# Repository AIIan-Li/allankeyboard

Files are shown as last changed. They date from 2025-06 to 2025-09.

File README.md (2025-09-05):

# Allan's keyboard
### About:
A 75% keyboard with a custom case. All parts under $150 USD, uses screw in stabilisers, and has akko v3 yellow switches along with M3 heatset inserts and screws. I made this project to learn more about CAD and making hardware projects. I thought it would be a reasonable next step after a macropad (was way harder actually) however I got to challenge myself and learn new things. 

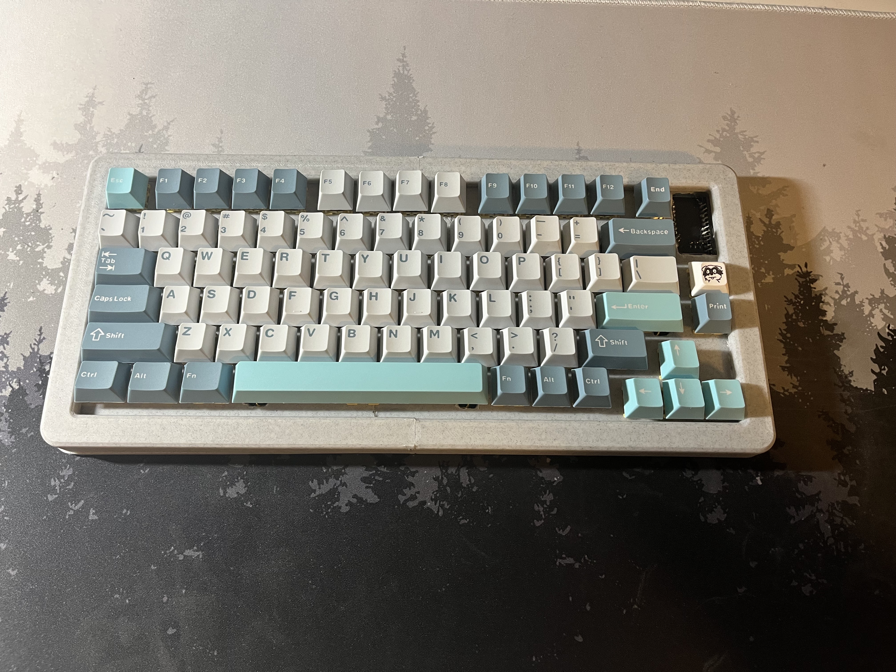
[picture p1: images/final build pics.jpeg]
final build

[project demo](https://youtu.be/CJazeotiTts)
[good project demo](https://youtu.be/POquT2XbD1o)
### Case:

The case was made in Fusion 360 and is gasket mounted. 8 screws to ensure the keyboard is secure when printing in two parts. 

### Firmware:

The firmware was made with KMK however I intend to recreate firmware in ZMK for full bluetooth capabilities( I am currently learning as I don't want to just copilot/vibecode everything)

### Images:

Schematic
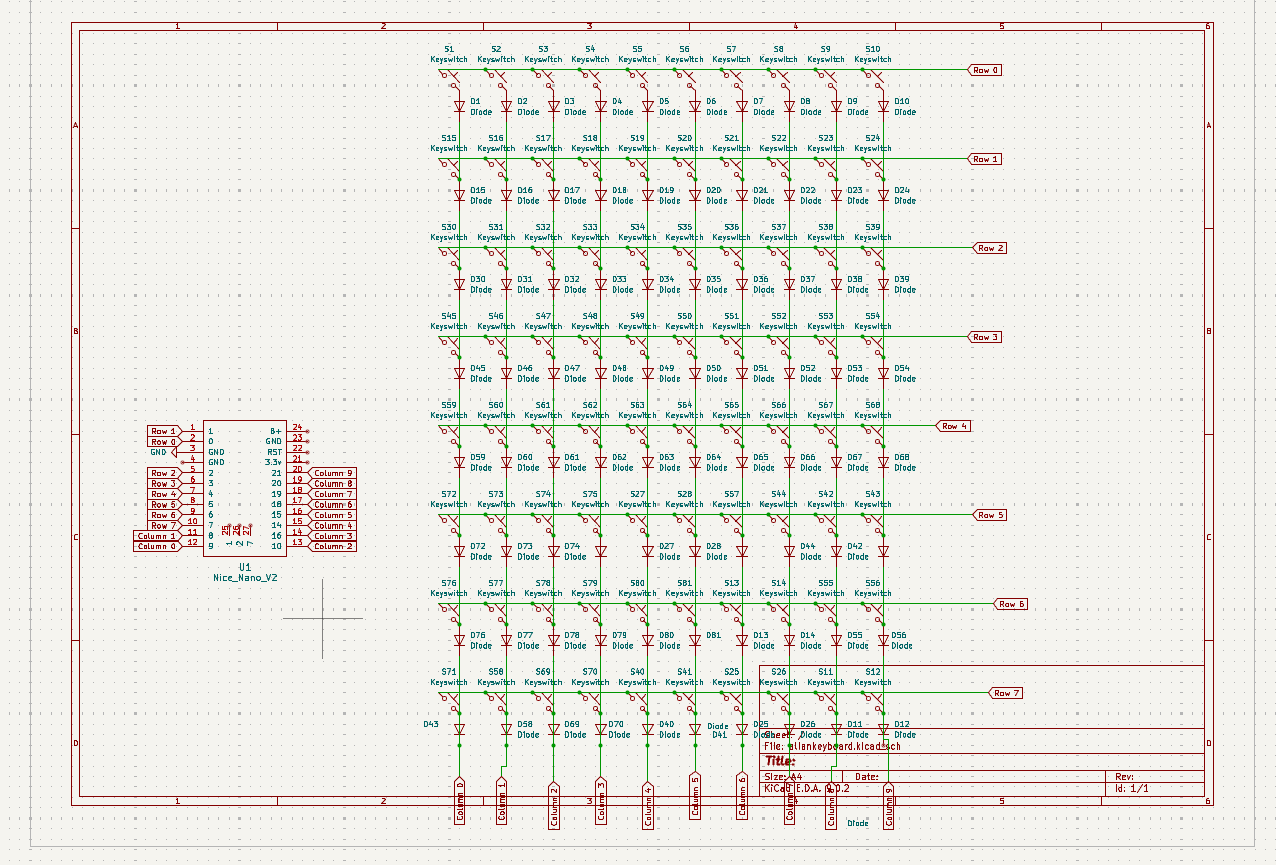
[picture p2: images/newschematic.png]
schematic


PCB
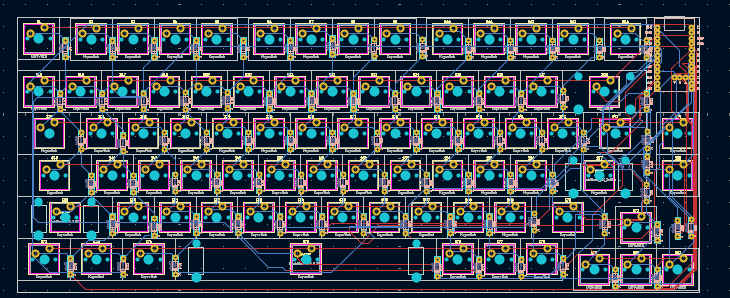
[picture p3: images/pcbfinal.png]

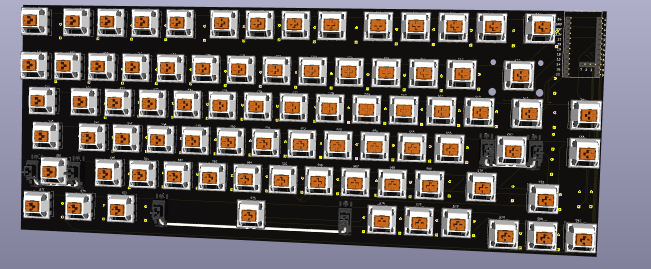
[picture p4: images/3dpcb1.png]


Case
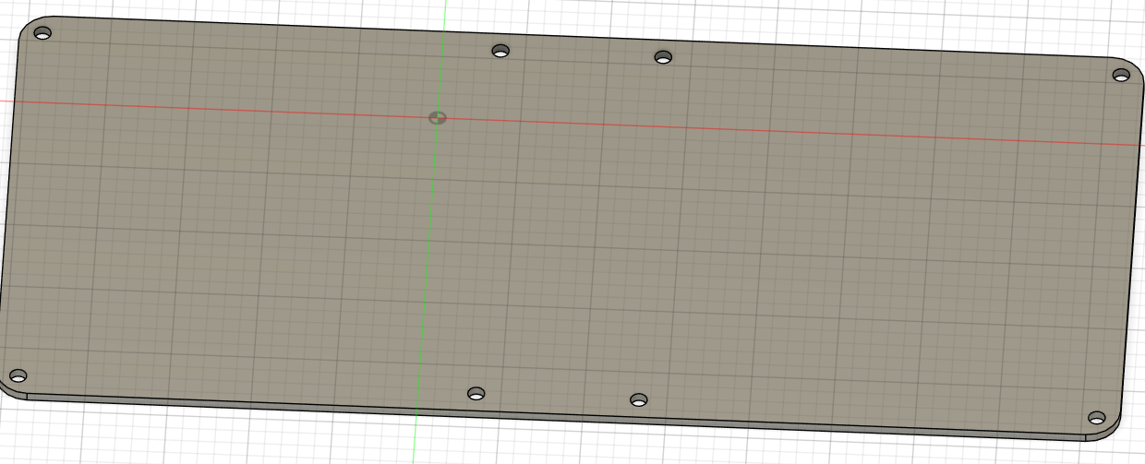
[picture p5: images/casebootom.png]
case

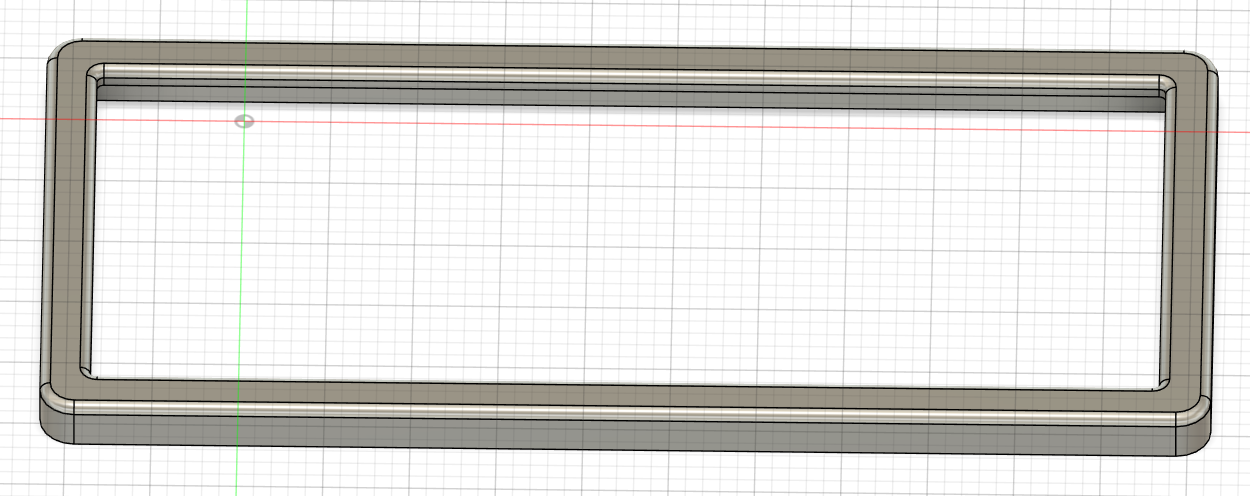
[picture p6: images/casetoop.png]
case

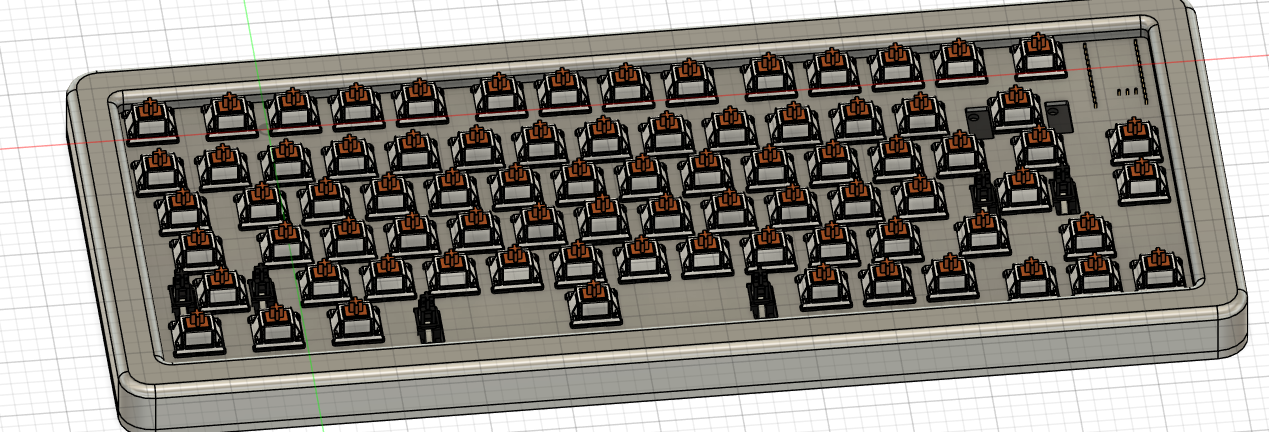
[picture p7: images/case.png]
case


### BOM:
| Item | Cost (USD) | Cost (CAD) | Link |
| --- | --- | --- | --- |
| Akko V3 Cream Yellow Switches | \$33.00 | \$45.00 | [https://www.amazon.ca/Akko-Keyboard-Dustproof-Mechanical-Switches/dp/B0C3H8NVJV/](https://www.amazon.ca/Akko-Keyboard-Dustproof-Mechanical-Switches/dp/B0C3H8NVJV/) |
| 3D Printer Filament (PLA 1kg) | \$21.00 | \$28.00 | [https://www.amazon.ca/ELEGOO-Filament-Dimensional-Accuracy-Compatible/dp/B0BM4F65SL/](https://www.amazon.ca/ELEGOO-Filament-Dimensional-Accuracy-Compatible/dp/B0BM4F65SL/) |
| PCB x5 (min quantity) | \$0.00 | \$0.00 | [https://jlcpcb.com](https://jlcpcb.com) |
| 1N4148 Diodes x100 | \$1.50 | \$2.00 | [https://www.aliexpress.com/item/1005003194692663.html](https://www.aliexpress.com/item/1005003194692663.html) |
| Durock V3 Stabilizers | \$10.00 | \$13.00 | [https://www.aliexpress.com/item/1005002192386317.html](https://www.aliexpress.com/item/1005002192386317.html) |
| Heatset Inserts | \$5.10 | \$7.00 | [https://www.aliexpress.com/item/1005006472962973.html](https://www.aliexpress.com/item/1005006472962973.html) |
| nice!nano v2 | \$44.00 | \$60.00 | [https://typeractive.xyz/products/nice-nano](https://typeractive.xyz/products/nice-nano) |
| Keycaps | \$9.00 | \$12.00 | [https://www.aliexpress.com/item/1005007321700850.html](https://www.aliexpress.com/item/1005007321700850.html) |
| Screws | \$1.80 | \$2.50 | [https://www.aliexpress.com/item/4000056753202.html](https://www.aliexpress.com/item/4000056753202.html) |
| | | | |

| **Total (Shipping included)** | **\$123.60** | **\$170.00** |                                                                                                                                                                              |

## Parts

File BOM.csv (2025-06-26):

Bill of Materials / Allan keyboard
Allan Li
June 24 2025
Item Name | Purpose | Item Source | Quantity | cost USD(w/ shipping) | cost CAD(W/ shipping) | link
Akko V3 cream yellow switches | Mechanical switches | amazon | 2 | $33 | $45 | https://www.amazon.ca/Akko-Keyboard-Dustproof-Mechanical-Switches/dp/B0C3H8NVJV/
3D Printer Filament (PLA 1kg) | Print Case | Amazon | 1 | $21 | $28 | https://www.amazon.ca/ELEGOO-Filament-Dimensional-Accuracy-Compatible/dp/B0BM4F65SL/
PCB x5 (min quantity) | the pcb | JLCPCB | 1 | $0 | 0 | jlcpcb.com (free)
1N4148 Diodes x100 | they are diodes | Aliexpress | 2 | $1.5 | $2 | https://www.aliexpress.com/item/1005003194692663.html?
Durock V3 Stabilizers | Stability for longer keys | aliexpress | 1 | $10 | $13 | https://www.aliexpress.com/item/1005002192386317.html?
heatset inserts | for screwing in the screws | aliexpress | 1 | $5.1 | $7 | https://www.aliexpress.com/item/1005006472962973.html?
nice!nanov2 | mcu | typeractive | 1 | $44 | $60 | https://typeractive.xyz/products/nice-nano
keycaps | to click | aliexpress | 1 | $9 | $12 | https://www.aliexpress.com/item/1005007321700850.html?
screw | to secure case | aliexpress | 1 | 1.8 | 2.5 | https://www.aliexpress.com/item/4000056753202.html?
TOTAL |  |  |  | $123.6 | $170 | Shipping included even without coupons comes out to 143.6 USD

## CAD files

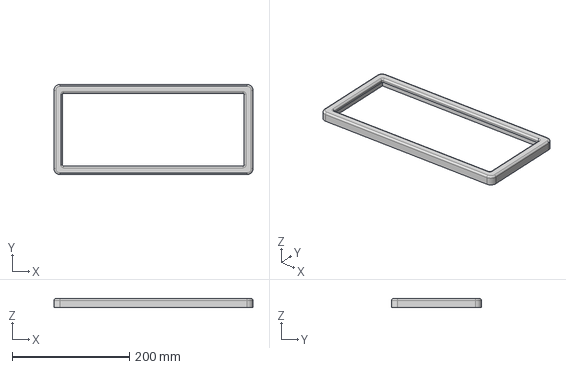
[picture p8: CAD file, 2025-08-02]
cad/super good casetop.step
339.0 x 153.5 x 15.0 mm

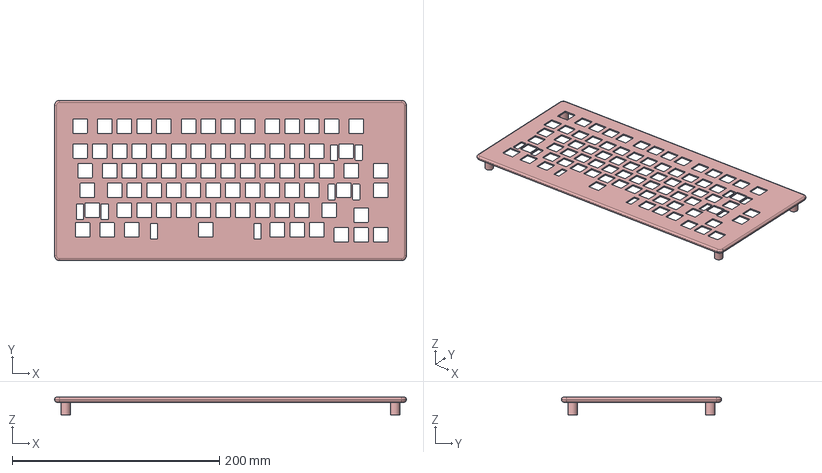
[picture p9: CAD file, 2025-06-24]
production/keyboard-top.step
340.0 x 155.0 x 17.0 mm

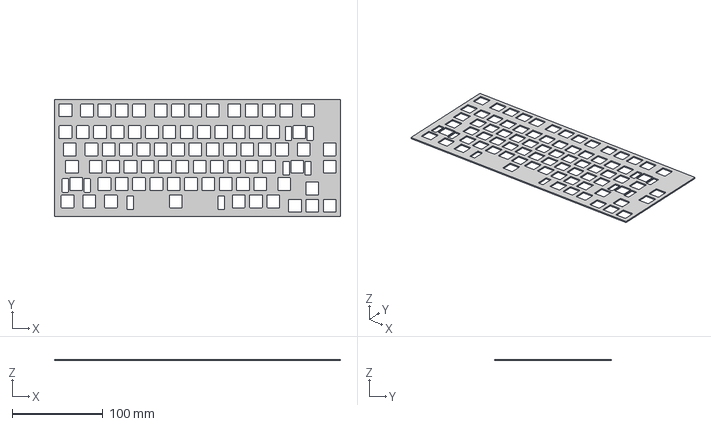
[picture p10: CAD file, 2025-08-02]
cad/plate-good.step
314.5 x 129.0 x 1.50 mm

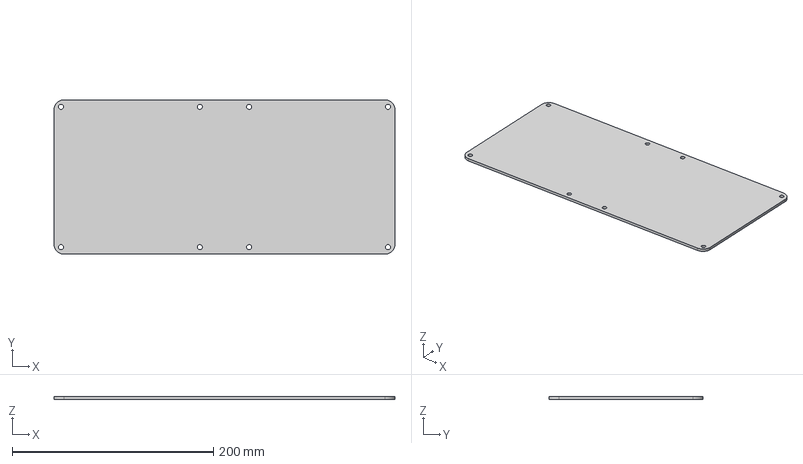
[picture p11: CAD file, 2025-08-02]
cad/super good casebottom.step
339.0 x 153.5 x 3.00 mm

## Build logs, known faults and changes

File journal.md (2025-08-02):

---
title: "Allan keyboard"
author: "Allan Li"
description: "Allan keyboard is a keyboard made for Allan"
created_at: "2025-06-09"
---
**Total time spent:1070 mins| 18 hours**
**Total time spent building: 4 hours** 

##June 9: research and getting started

So this is my first time making a keyboard, so I decided to do some thorough research to make sure that I fully understood everything, and made it how I wanted.
I'm thinking of a 75% keyboard, specificaly something similar to Epomakers, minus the rotary encoder.
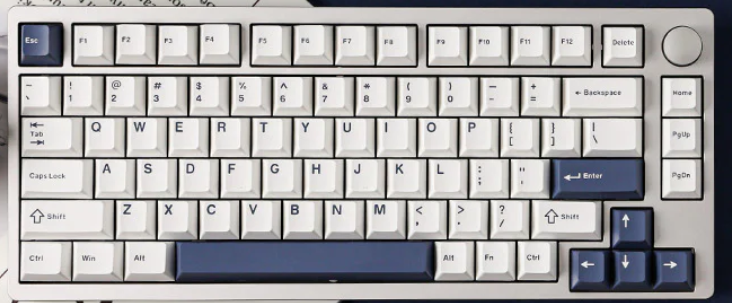
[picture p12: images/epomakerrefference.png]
refference image


I made an initial sketch for the matrix I also decided on the Nice Nano as the mcu
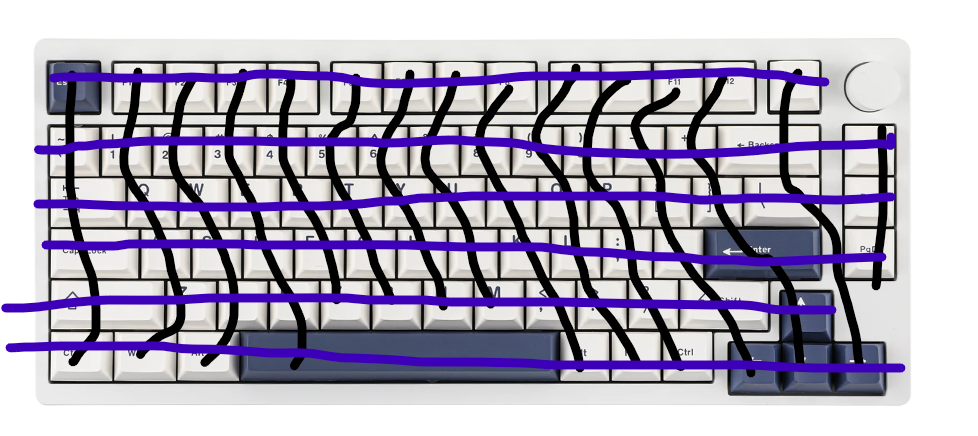
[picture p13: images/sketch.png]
matrix sketch

*Total time spent: 30 min*

##June 9: making the schematics

Not much to say, made the matrix and connected everything.
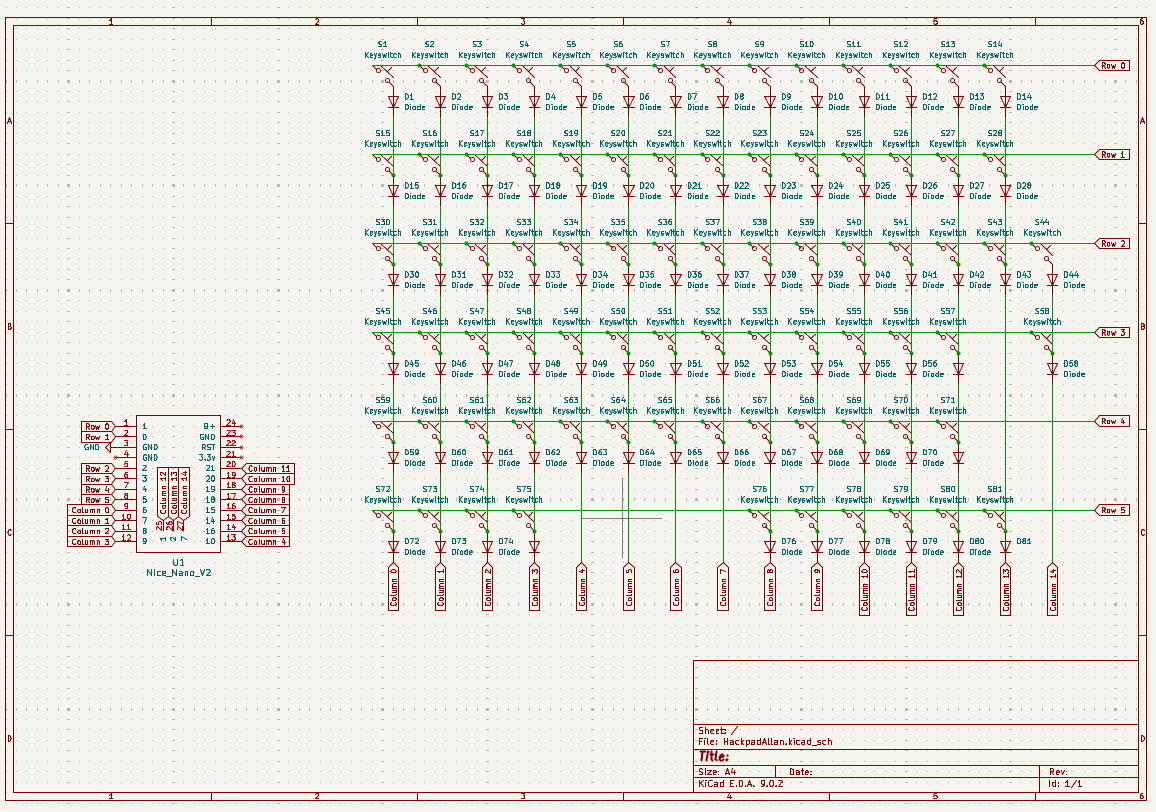
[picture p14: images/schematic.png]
schematic


*Total time spent:90 mins*

##June 10: starting the pcb

I started off by creating my design in Keyboard Layout Editor, then spent time trying to import it into KiCad.
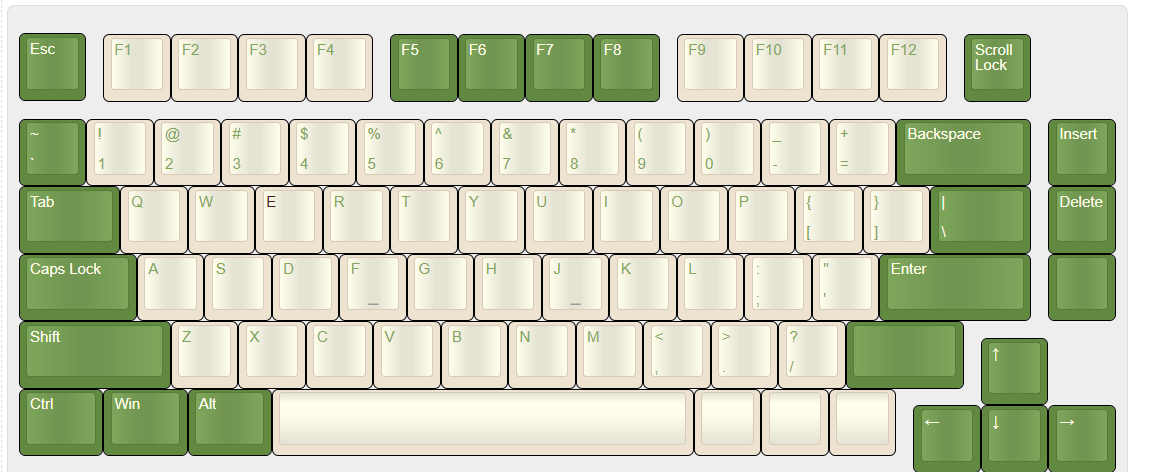
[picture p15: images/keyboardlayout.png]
KLE image


Took a really long time, I kept having problems with using the keboard placer plugin in Kicad,
had to redo footprints a bunch, set annotations and rearrange my schematic.
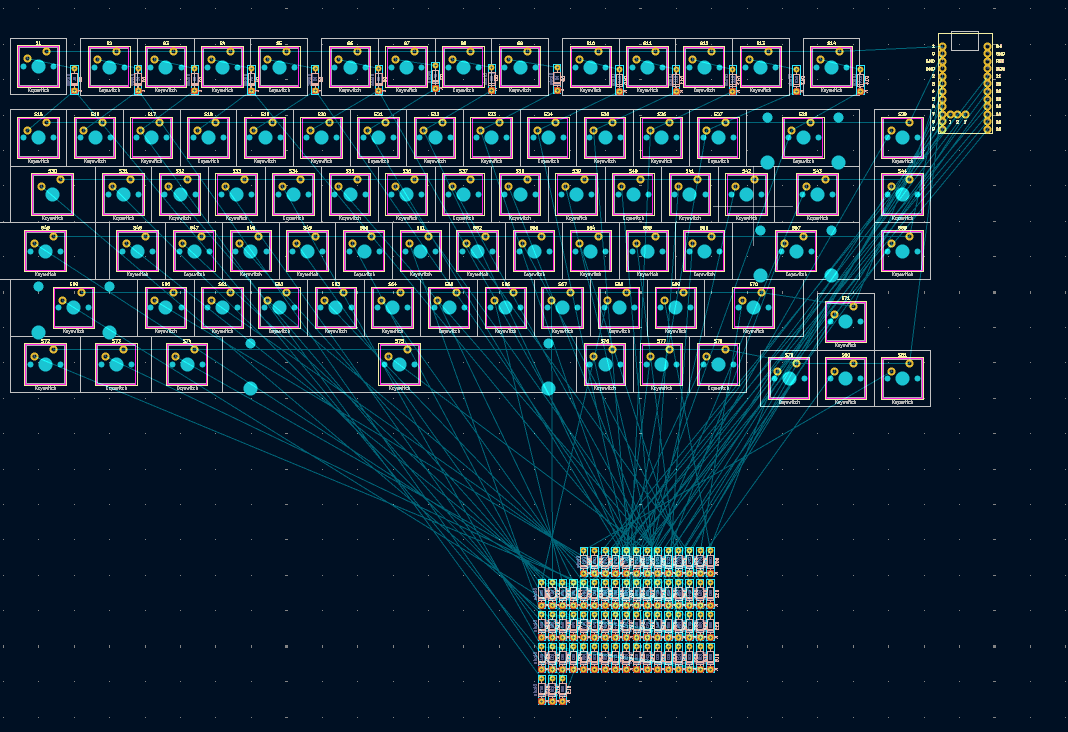
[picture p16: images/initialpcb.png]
initial pcb

Only have to move all diodes and route traces

Update: closed the window and clicked discard change because I was sure i only made one small thing. Will be restarting but oh well.

*Total time spent: 180 mins*

##june 11: Finishing the pcb

Finished positioning everything and routing all the traces. (made sure to save this time)

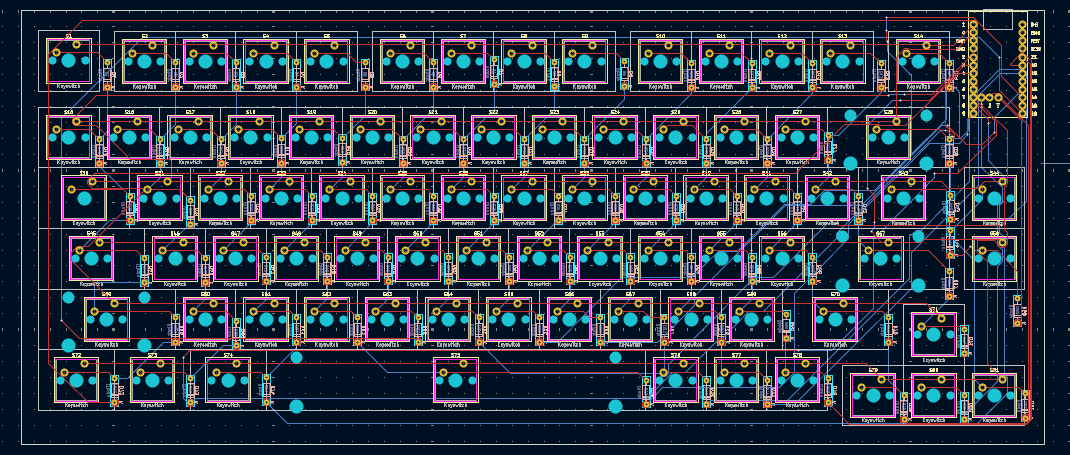
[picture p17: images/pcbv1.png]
pcb v1


Had a problem with the switches for 3d viewing, had to manually reassign each individual switch after downloading a library online
*Total time spent: 240 mins*

##June 23: making the case

It's been a while, Just finished up school so I can focus on doing this now
For my case, i wanted to have honeycomb walls, and make it snap together to be screwless.
So my pcb's dimmensions are apparently bigger than the plate I had in fusion, so it interferes with my screws

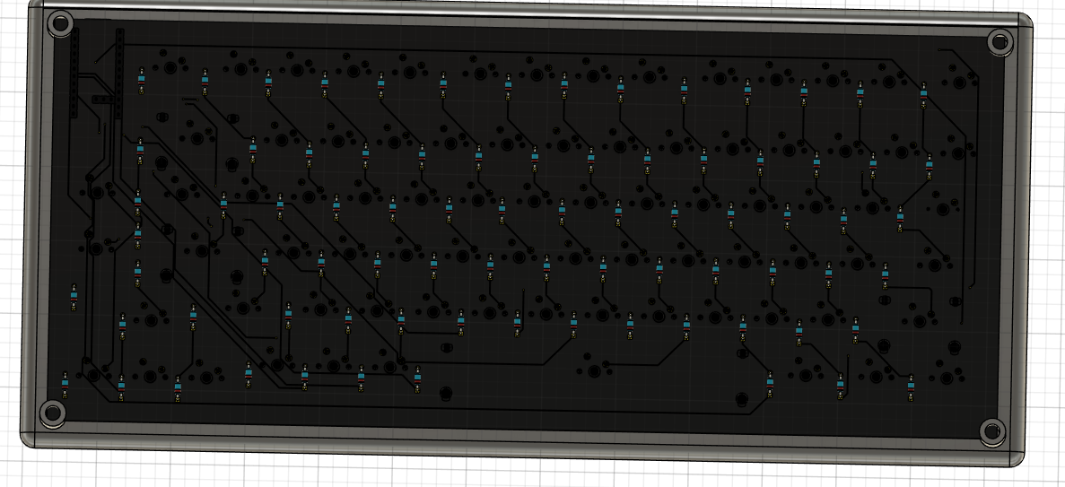
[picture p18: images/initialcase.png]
initial case


I will have to completely restart, however I hope it's easier seeing as I only need to change all the dimmensions
update: It was not a difficult fix, however looking at it it just looks really weird to me. I left a lot of space in my pcb design so I am going to get rid of it, and also I'll have to rewire all my traces.

*Total time spent: 200 mins*

##June 23: fixed pcb

I changed pcb to be on the bottom, and rerouted all the traces.

3d pcb
finished pcb
June 24 update: I <3 github, accidently overwrote and cleared all my kicad project files (idk how tbh) almost had me stressing for a minute there

*Total time spent: 60 mins*

##June 24: finishing the case:

I created a honeycomb pattern for the case and finished polishing everything up! 
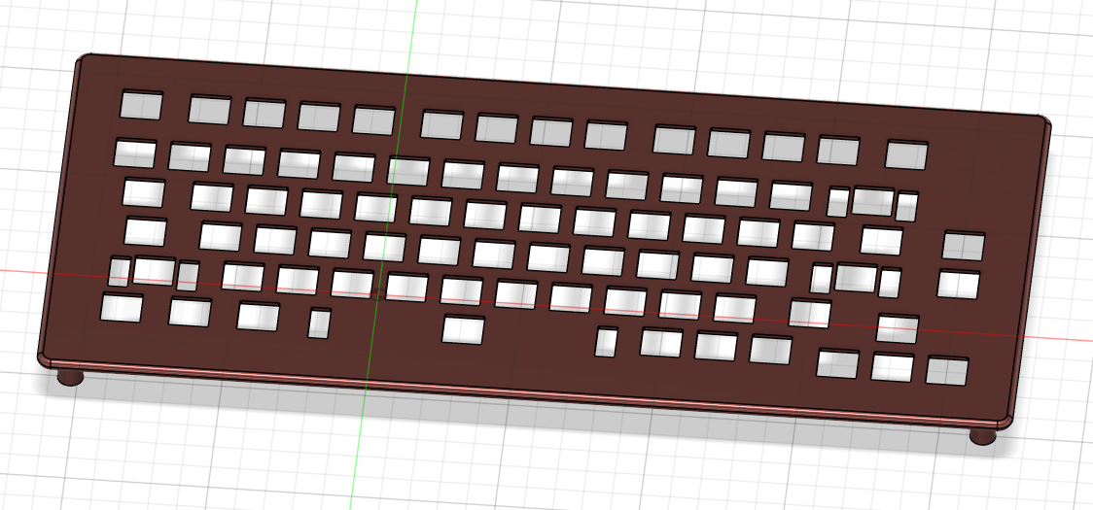
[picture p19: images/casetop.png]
case top

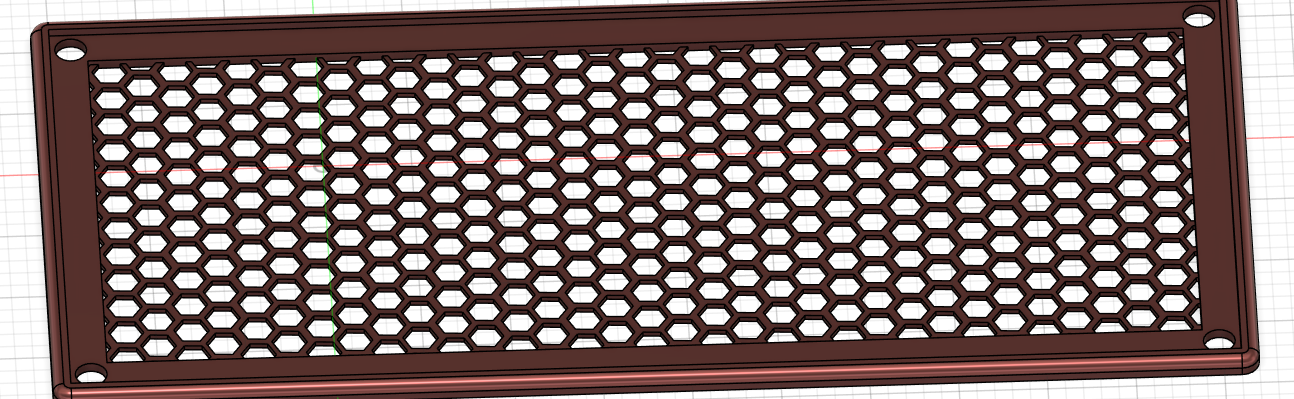
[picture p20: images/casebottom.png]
case bottom

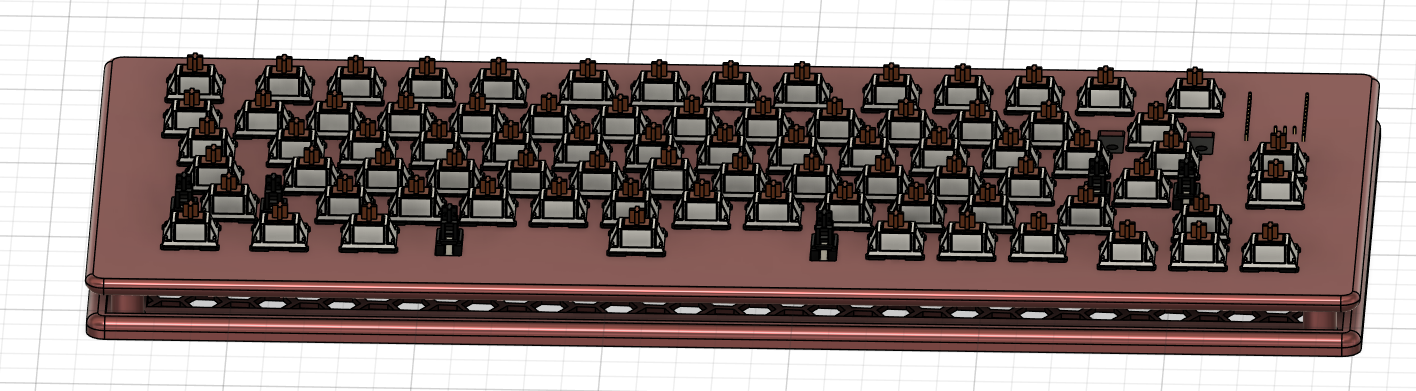
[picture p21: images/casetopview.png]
case top view

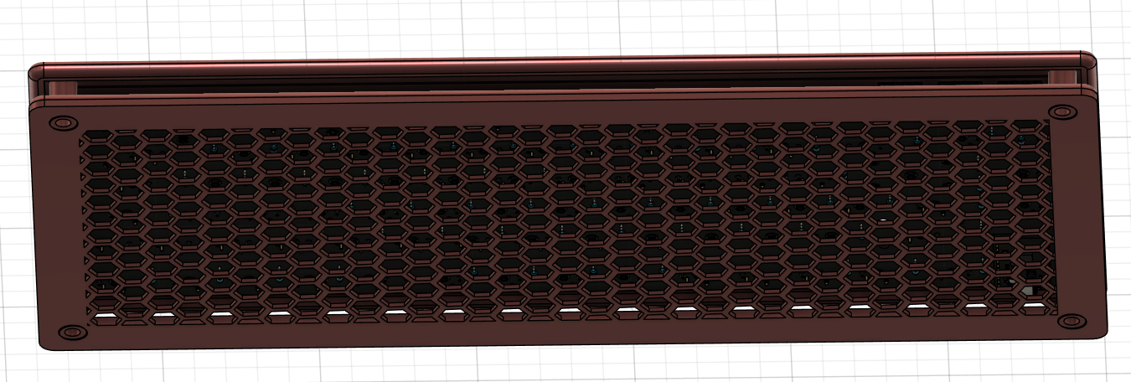
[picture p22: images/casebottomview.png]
case bottom view


*Total time spent: 120mins* 

##June 24: big problem time

So I'm trying to write my kmk, when I look at the schematic of my nicenano and notice that the 3 middle pins aren't unique gpio pins. I made my matrix based off my actual keyboard layout rather than optimising it so I'm left with 21 gpio pins vs 18 required, which would fit on the mcu.
I can A: keep nice nano, recreate schematic, reformat and fully recreate pcb
or B: change mcu from nice!nano to something like a pico 
After debating for a while, I decided to stick with the nice nano since I wouldn't have to redo my case dimmensions and keep it more compact 

Fixed and pcb  
new schematic

**Total time spent: 90 mins** 

##June 24: making the firmware

Not too much to say, It was a bit complicated trying to properly map the matrix, as I had to rearrange lots of things and I didn't completely restart (last entry) in theory everything should work fine however i will have to wait until I build my keyboard to see.

**Total time spent: 60mins** 

##July 28: building the project

I decided the old case wasn't good enoug (after my friend pointed out) because It didn't necessarily have a real case and the plate was acting as one. 
Future allan after building the keyboard: this was the greatest decision ever made for so many reasons, details later in journal 
new case
new case
new case

I soldered the diodes and mcu, I'm still finishing the prints so I loaded the firmware onto the mcu.
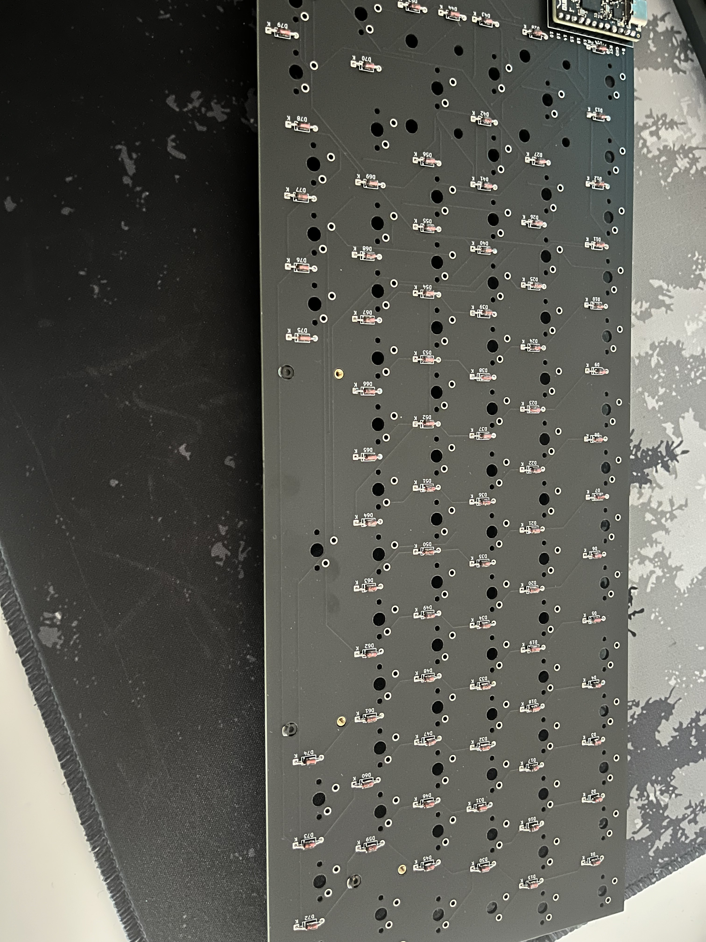
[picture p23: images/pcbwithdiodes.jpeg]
pcb with diodes

side note: I just finished soldering the diodes and the mcu. I realised there were two extra pins that did not have headers and I was very scared I messed up and would have to resolder. Checked the pinout and there is just two random pins that aren't supposed to be soldered for some reason

**Total time spent: 60mins**

##July 30: finishing the project 

I started off by assembling the case. I didn't take a picture of this specifically but each part was printed in two bc it didn't fit on the printer. It was really flimsy so I pretty much melted the plastic with a soldering iron fusing the parts together. 
time: 30 mins

I was busy snapping all my switches into my plate when I noticed the plate began to start bending due to the outward pressure on the walls of each cutout. I tried to fix this by aliging the plate over the plate over the pcb and inserting the switch like that, however this didn't work and I left it curved. 
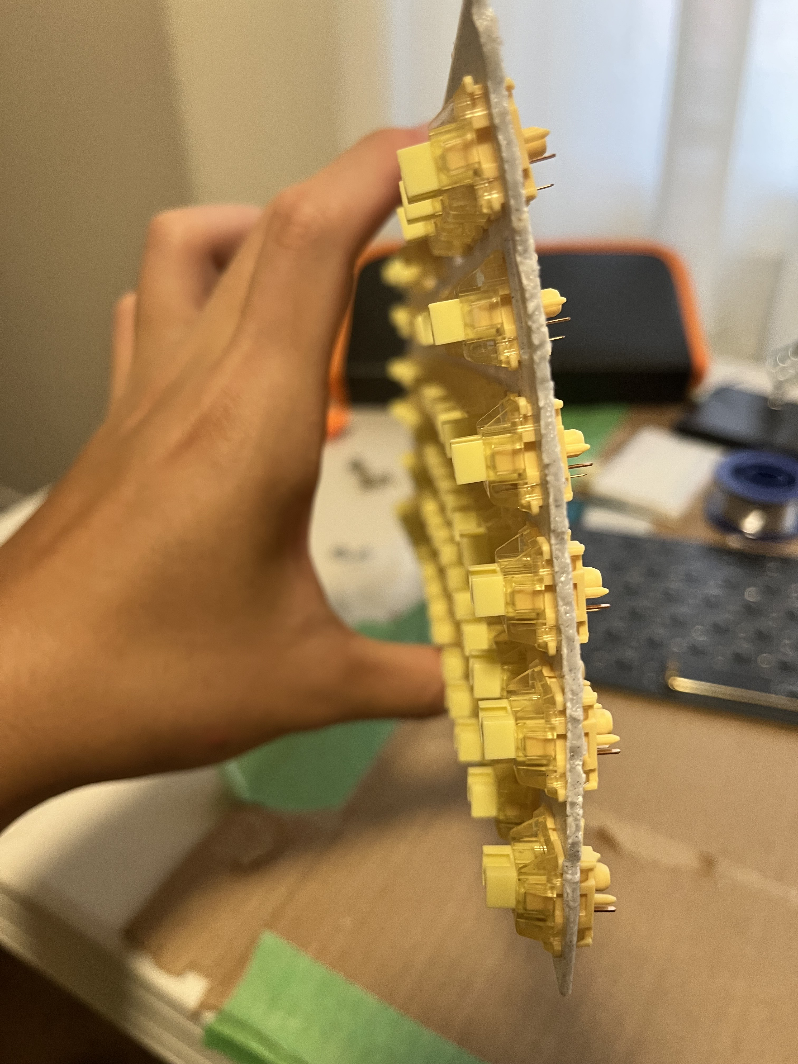
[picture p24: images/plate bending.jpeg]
bending plate


Fortunately, after soldering the switches into the pcb, It was more stable and no longer as curved

time : 120 mins

for the final part, I just had to add heatset inserts, screws, and put everything together. 
I'd say this part went ok, because of the plate bending from earlier I had to push down just to be able to screw in the case bottom. It actually created a gap between top + bottom case so I kind of just stuck my soldering Iron into the case and it fixed it. 

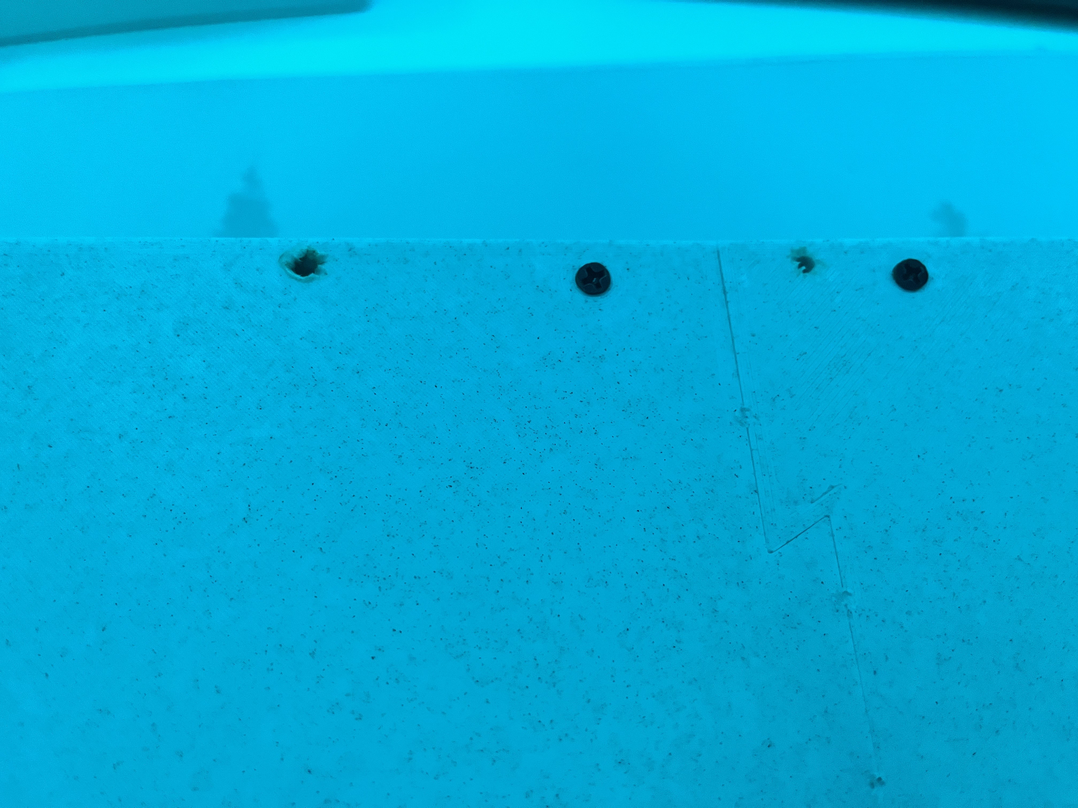
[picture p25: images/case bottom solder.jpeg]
case bottom


I added the keycaps and I was finally done my keyboard! 

Final result 
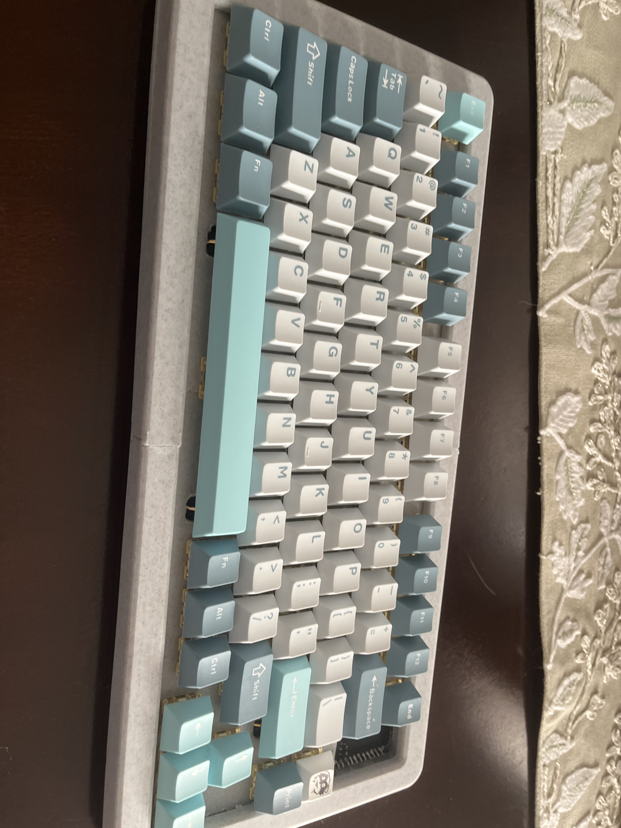
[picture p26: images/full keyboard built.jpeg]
keyboard finished


This goes with the part where I soldered the switches but I just realised and figured it goes better with the picture I have. Becase I bottom mounted the mcu, the pins poked out slightly too much that it interfered with the plate. I tried cutting the pins shorter and ended up breaking my wire cutters. I then used pliers to bend them in half but still noting worked. I had to cut out that part of my keyboard and leave it exposed. I do plan to create a new plate top, this time covering over the new empty hole + additional features. 

time spent : 30 mins

**total time spent: 180 mins**

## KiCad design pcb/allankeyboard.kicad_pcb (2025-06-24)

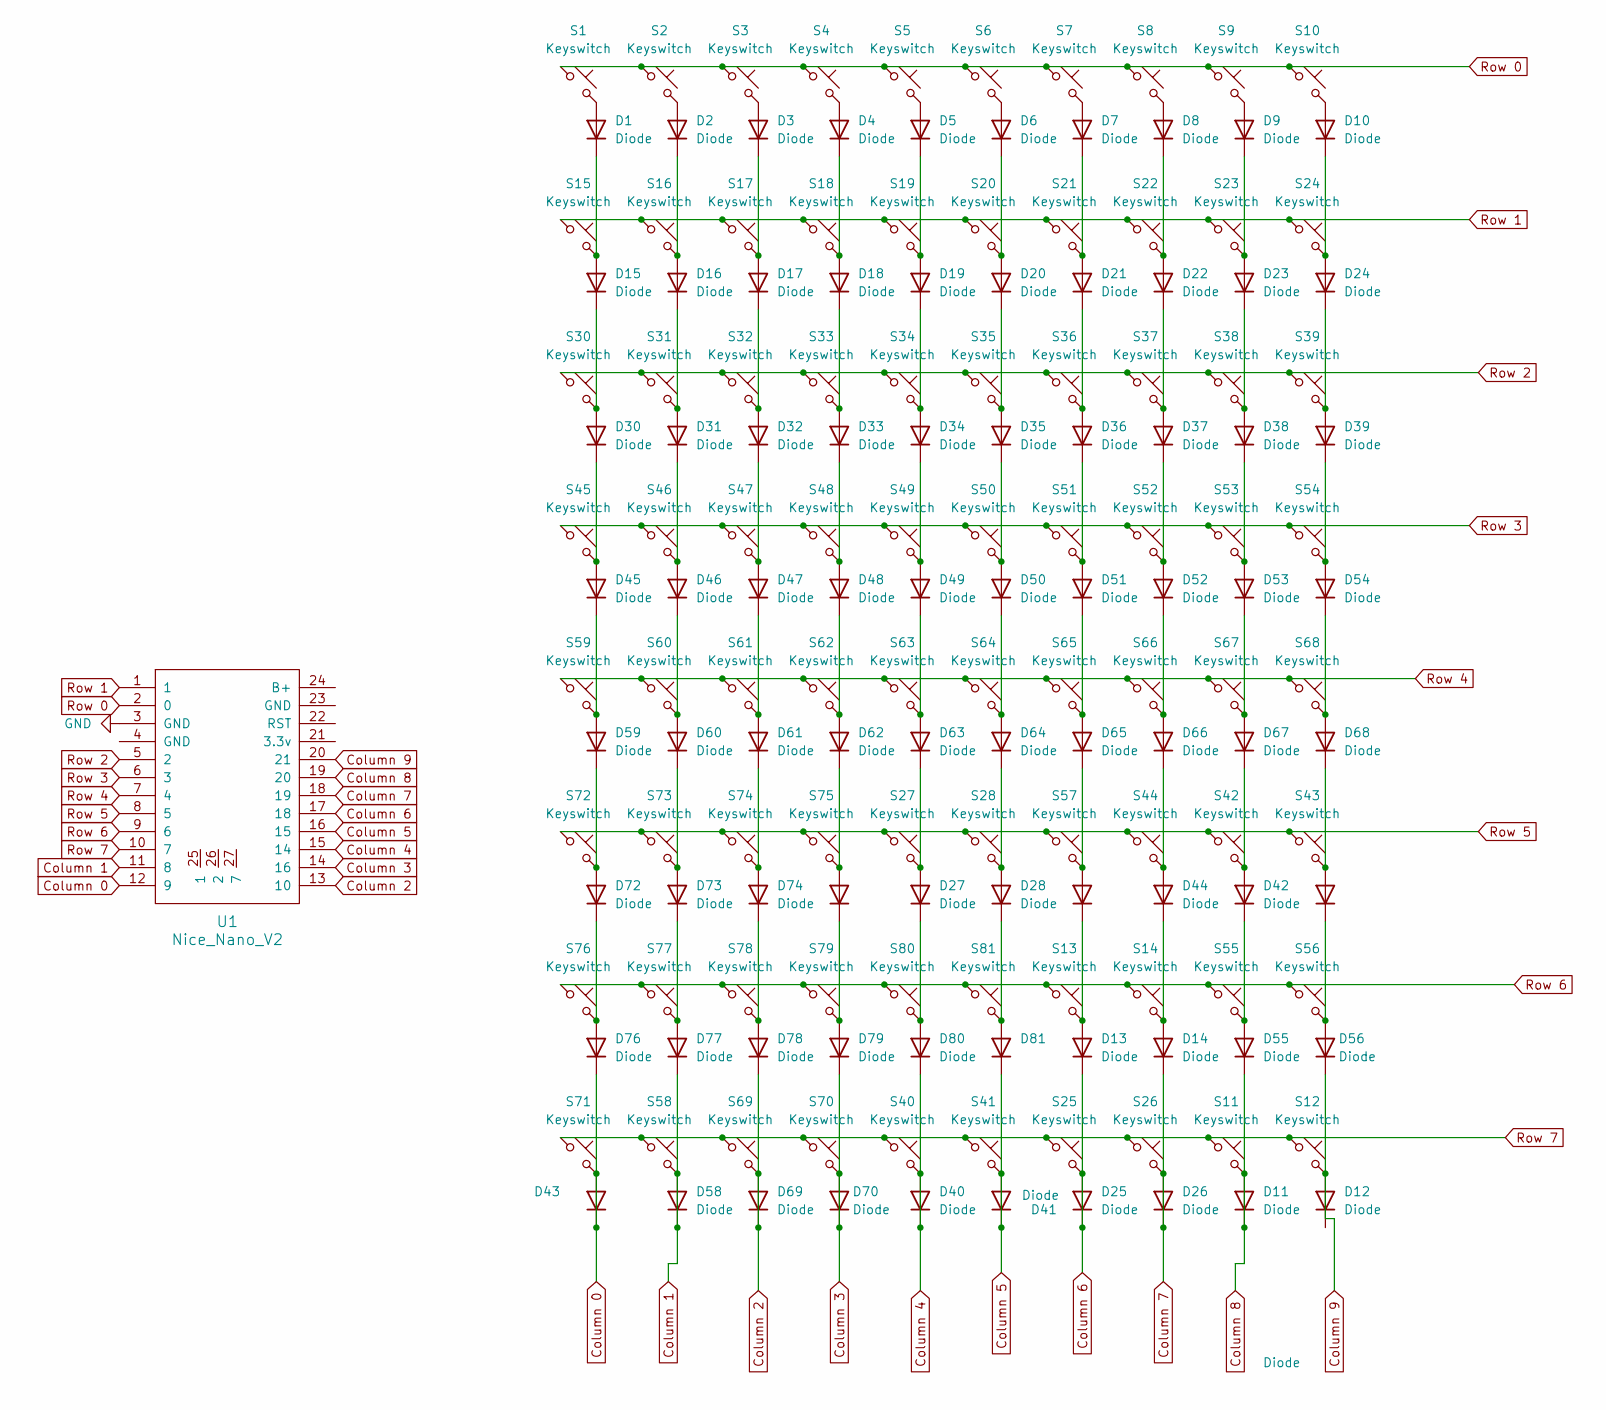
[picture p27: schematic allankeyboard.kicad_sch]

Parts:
D1, D2, D3, D4, D5, D6, D7, D8, D9, D10, D11, D12, D13, D14, D15, D16, D17, D18, D19, D20, D21, D22, D23, D24, D25, D26, D27, D28, D30, D31, D32, D33, D34, D35, D36, D37, D38, D39, D40, D41, D42, D43, D44, D45, D46, D47, D48, D49, D50, D51, D52, D53, D54, D55, D56, D57, D58, D59, D60, D61, D62, D63, D64, D65, D66, D67, D68, D69, D70, D71, D72, D73, D74, D75, D76, D77, D78, D79, D80, D81: Diode; D_DO-35_SOD27_P7.62mm_Horizontal
S1, S2, S3, S4, S5, S6, S7, S8, S9, S10, S11, S12, S13, S14, S15, S16, S17, S18, S19, S20, S21, S22, S23, S24, S25, S26, S27, S31, S32, S33, S34, S35, S36, S37, S38, S39, S40, S41, S42, S44, S46, S47, S48, S49, S50, S51, S52, S53, S54, S55, S56, S58, S60, S61, S62, S63, S64, S65, S66, S67, S68, S69, S71, S76, S77, S78, S79, S80, S81: Keyswitch; SW_Cherry_MX_1.00u_PCB
S28: Keyswitch; SW_Cherry_MX_2.00u_PCB
S30: Keyswitch; SW_Cherry_MX_1.50u_Plate
S43: Keyswitch; SW_Cherry_MX_1.50u_PCB
S45, S70: Keyswitch; SW_Cherry_MX_1.75u_PCB
S57, S59: Keyswitch; SW_Cherry_MX_2.25u_PCB
S72, S73, S74: Keyswitch; SW_Cherry_MX_1.25u_PCB
S75: Keyswitch; SW_Cherry_MX_6.25u_PCB
U1: Nice_Nano_V2

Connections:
Column 0: D71.1 (K), D71.2 (A), D76.1 (K), S71.2, U1.12 (9)
Column 1: D58.1 (K), D58.2 (A), D77.1 (K), S58.2, U1.11 (8)
Column 2: D69.1 (K), D69.2 (A), D78.1 (K), S69.2, U1.13 (10)
Column 3: D70.1 (K), D70.2 (A), D79.1 (K), S70.2, U1.14 (16)
Column 4: D40.1 (K), D40.2 (A), D80.1 (K), S40.2, U1.15 (14)
Column 5: D41.1 (K), D41.2 (A), D81.1 (K), S41.2, U1.16 (15)
Column 6: D13.1 (K), D25.1 (K), D25.2 (A), S25.2, U1.17 (18)
Column 7: D14.1 (K), D26.1 (K), D26.2 (A), S26.2, U1.18 (19)
Column 8: D11.1 (K), D11.2 (A), D55.1 (K), S11.2, U1.19 (20)
Column 9: D12.2 (A), D56.1 (K), S12.2, U1.20 (21)
GND: U1.3 (GND)
unnamed: D1.2 (A), S1.2
unnamed: D1.1 (K), D15.2 (A), S15.2
unnamed: D2.2 (A), S2.2
unnamed: D3.2 (A), S3.2
unnamed: D4.2 (A), S4.2
unnamed: D5.2 (A), S5.2
unnamed: D6.2 (A), S6.2
unnamed: D7.2 (A), S7.2
unnamed: D8.2 (A), S8.2
unnamed: D9.2 (A), S9.2
unnamed: D10.2 (A), S10.2
unnamed: D10.1 (K), D24.2 (A), S24.2
unnamed: D13.2 (A), D57.1 (K), S13.2
unnamed: D14.2 (A), D44.1 (K), S14.2
unnamed: D15.1 (K), D30.2 (A), S30.2
unnamed: D2.1 (K), D16.2 (A), S16.2
unnamed: D16.1 (K), D31.2 (A), S31.2
unnamed: D3.1 (K), D17.2 (A), S17.2
unnamed: D17.1 (K), D32.2 (A), S32.2
unnamed: D4.1 (K), D18.2 (A), S18.2
unnamed: D18.1 (K), D33.2 (A), S33.2
unnamed: D5.1 (K), D19.2 (A), S19.2
unnamed: D19.1 (K), D34.2 (A), S34.2
unnamed: D6.1 (K), D20.2 (A), S20.2
unnamed: D20.1 (K), D35.2 (A), S35.2
unnamed: D7.1 (K), D21.2 (A), S21.2
unnamed: D21.1 (K), D36.2 (A), S36.2
unnamed: D8.1 (K), D22.2 (A), S22.2
unnamed: D22.1 (K), D37.2 (A), S37.2
unnamed: D9.1 (K), D23.2 (A), S23.2
unnamed: D23.1 (K), D38.2 (A), S38.2
unnamed: D24.1 (K), D39.2 (A), S39.2
unnamed: D27.2 (A), D63.1 (K), S27.2
unnamed: D27.1 (K), D80.2 (A), S80.2
unnamed: D28.2 (A), D64.1 (K), S28.2
unnamed: D28.1 (K), D81.2 (A), S81.2
unnamed: D30.1 (K), D45.2 (A), S45.2
unnamed: D31.1 (K), D46.2 (A), S46.2
unnamed: D32.1 (K), D47.2 (A), S47.2
unnamed: D33.1 (K), D48.2 (A), S48.2
unnamed: D34.1 (K), D49.2 (A), S49.2
unnamed: D35.1 (K), D50.2 (A), S50.2
unnamed: D36.1 (K), D51.2 (A), S51.2
unnamed: D37.1 (K), D52.2 (A), S52.2
unnamed: D38.1 (K), D53.2 (A), S53.2
unnamed: D39.1 (K), D54.2 (A), S54.2
unnamed: D42.2 (A), D67.1 (K), S42.2
unnamed: D42.1 (K), D55.2 (A), S55.2
unnamed: D43.2 (A), D68.1 (K), S43.2
unnamed: D43.1 (K), D56.2 (A), S56.2
unnamed: D44.2 (A), D66.1 (K), S44.2
unnamed: D45.1 (K), D59.2 (A), S59.2
unnamed: D46.1 (K), D60.2 (A), S60.2
unnamed: D47.1 (K), D61.2 (A), S61.2
unnamed: D48.1 (K), D62.2 (A), S62.2
unnamed: D49.1 (K), D63.2 (A), S63.2
unnamed: D50.1 (K), D64.2 (A), S64.2
unnamed: D51.1 (K), D65.2 (A), S65.2
unnamed: D52.1 (K), D66.2 (A), S66.2
unnamed: D53.1 (K), D67.2 (A), S67.2
unnamed: D54.1 (K), D68.2 (A), S68.2
unnamed: D57.2 (A), D65.1 (K), S57.2
unnamed: D59.1 (K), D72.2 (A), S72.2
unnamed: D60.1 (K), D73.2 (A), S73.2
unnamed: D61.1 (K), D74.2 (A), S74.2
unnamed: D62.1 (K), D75.2 (A), S75.2
unnamed: D72.1 (K), D76.2 (A), S76.2
unnamed: D73.1 (K), D77.2 (A), S77.2
unnamed: D74.1 (K), D78.2 (A), S78.2
unnamed: D75.1 (K), D79.2 (A), S79.2
Row 0: S1.1, S2.1, S3.1, S4.1, S5.1, S6.1, S7.1, S8.1, S9.1, S10.1, U1.2 (0)
Row 1: S15.1, S16.1, S17.1, S18.1, S19.1, S20.1, S21.1, S22.1, S23.1, S24.1, U1.1
Row 2: S30.1, S31.1, S32.1, S33.1, S34.1, S35.1, S36.1, S37.1, S38.1, S39.1, U1.5 (2)
Row 3: S45.1, S46.1, S47.1, S48.1, S49.1, S50.1, S51.1, S52.1, S53.1, S54.1, U1.6 (3)
Row 4: S59.1, S60.1, S61.1, S62.1, S63.1, S64.1, S65.1, S66.1, S67.1, S68.1, U1.7 (4)
Row 5: S27.1, S28.1, S42.1, S43.1, S44.1, S57.1, S72.1, S73.1, S74.1, S75.1, U1.8 (5)
Row 6: S13.1, S14.1, S55.1, S56.1, S76.1, S77.1, S78.1, S79.1, S80.1, S81.1, U1.9 (6)
Row 7: S11.1, S12.1, S25.1, S26.1, S40.1, S41.1, S58.1, S69.1, S70.1, S71.1, U1.10 (7)

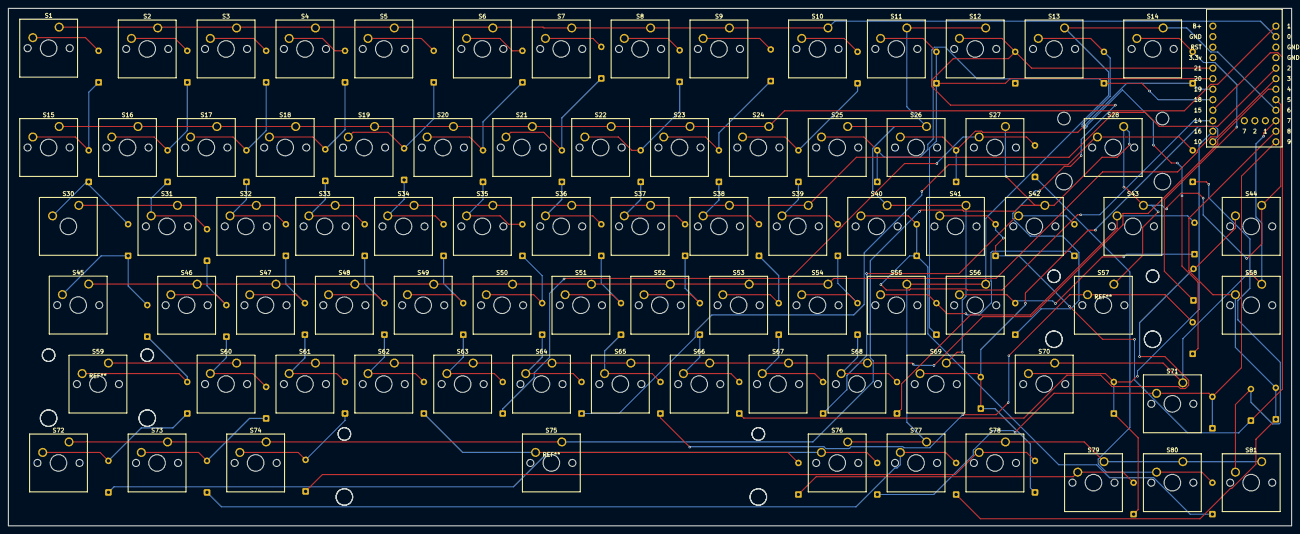
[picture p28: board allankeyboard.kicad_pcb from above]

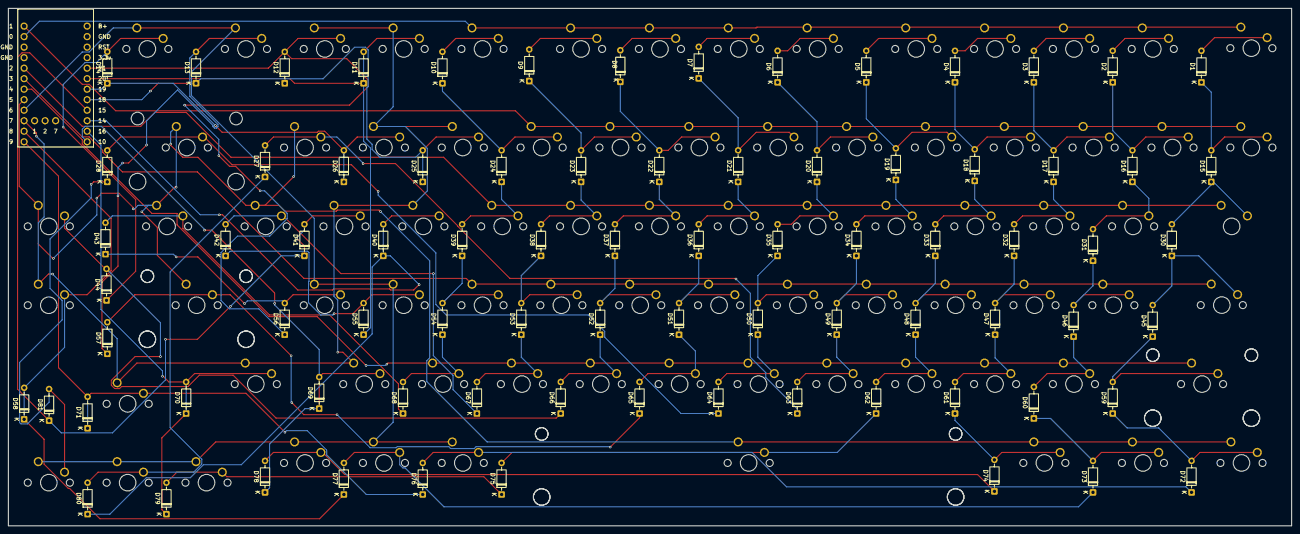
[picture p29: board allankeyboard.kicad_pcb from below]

Board: 2 copper layers, 310.0 x 125.0 mm, 161 parts (81 on the bottom side), 88 nets.

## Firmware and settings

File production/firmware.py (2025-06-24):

import board
from kmk.kmk_keyboard import KMKKeyboard
from kmk.scanners import DiodeOrientation
from kmk.keys import KC

keyboard = KMKKeyboard()

# Row GPIOs (Row 0–7)
keyboard.row_pins = [
    board.GP1,  # Row 0
    board.GP0,  # Row 1
    board.GP2,  # Row 2
    board.GP3,  # Row 3
    board.GP4,  # Row 4
    board.GP5,  # Row 5
    board.GP6,  # Row 6
    board.GP7,  # Row 7
]

# Column GPIOs (Col 0–9)
keyboard.col_pins = [
    board.GP8,   # Col 0
    board.GP9,   # Col 1
    board.GP10,  # Col 2
    board.GP16,  # Col 3
    board.GP14,  # Col 4
    board.GP15,  # Col 5
    board.GP18,  # Col 6
    board.GP19,  # Col 7
    board.GP20,  # Col 8
    board.GP21,  # Col 9
]

keyboard.diode_orientation = DiodeOrientation.COL2ROW

# Keymap (8 rows × 10 columns)
keyboard.keymap = [
    [KC.ESC,  KC.F1,  KC.F2,  KC.F3,  KC.F4,   KC.F5,   KC.F6,   KC.F7,   KC.F8,   KC.F9],    
    [KC.GRV,  KC.N1,  KC.N2,  KC.N3,  KC.N4,   KC.N5,   KC.N6,   KC.N7,   KC.N8,   KC.N9],    
    [KC.TAB,  KC.Q,   KC.W,   KC.E,   KC.R,    KC.T,    KC.Y,    KC.U,    KC.I,    KC.O],     
    [KC.CAPS, KC.A,   KC.S,   KC.D,   KC.F,    KC.G,    KC.H,    KC.J,    KC.K,    KC.L],     
    [KC.LSFT, KC.Z,   KC.X,   KC.C,   KC.V,    KC.B,    KC.N,    KC.M,    KC.COMM, KC.DOT],   
    [KC.LCTL, KC.LGUI,KC.LALT,KC.SPC, KC.RALT, KC.FN0,  KC.RCTL, KC.LEFT, KC.DOWN, KC.RIGHT],
    [KC.NO,   KC.NO,  KC.NO,  KC.NO,  KC.NO,   KC.NO,   KC.NO,   KC.NO,   KC.NO,   KC.NO],    
    [KC.NO,   KC.NO,  KC.NO,  KC.NO,  KC.NO,   KC.NO,   KC.NO,   KC.NO,   KC.NO,   KC.NO],    
]

if __name__ == '__main__':
    keyboard.go()

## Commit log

2025-06-24 added journal.md and pcb files
    [allankeyboard.kicad_pcb, allankeyboard.kicad_sch]
2025-06-24 Finished Jounraling, added all step files and complete BOM
    [BOM.csv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]
2025-06-24 fix BOM formating
    [BOM.csv]
2025-06-24 fix bom (again)
    [BOM.csv]
2025-06-26 added links to BOM
    [BOM.csv]
2025-06-26 added bom
2025-08-02 completed journal updated everything
    [allankeyboardmodel.step, keyboard-bottom.step, keyboard-top.step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]
